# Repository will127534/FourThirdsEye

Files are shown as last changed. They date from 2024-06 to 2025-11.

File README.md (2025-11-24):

# FourThirdsEye: Opensource Micro Four Thirds camera module based on IMX294
_DSC0208

## Introduction
Welcome to the **FourThirdsEye** project, an open-source camera board designed for Raspberry Pi 5 and Raspberry Pi Compute Module 4 boards using a Micro Four Thirds format image sensor IMX294. This project aims to provide a high-quality and accessible camera module for advanced Raspberry Pi projects. The board is designed using KiCad v8.

FourThirdsEye captures 10.7 Mpix images and 4K (4096 x 2160) videos with improved low-light performance and dynamic range (4.63 um pixel size). It's perfect for photography enthusiasts, developers, and makers who want to level up their Raspberry Pi projects with a powerful camera.

Also see [Quick Start Guide](https://github.com/will127534/FourThirdsEye/wiki/FourThirdsEye-Quick-Start-Guide)

## Features
* **Open-source hardware and software**
* IMX294 sensor
* Integrated TMP117 temperature sensor
* Integrated ICM-42688-P 6-axis IMU with FSYNC connected to sensor's VSYNC
* Compatible with Raspberry Pi5 and Raspberry Pi Compute Module 4 boards with a 22-pin FPC connector and 4-lane MIPI-CSI (same pinout as Raspberry Pi Compute Module 4 IO Board)

## Notes
* Gerber, BOM and CPL file for JLCPCB is under [/Gerber](/Gerber)
* [Interactive BOM](https://htmlpreview.github.io/?https://github.com/will127534/FourThirdsEye/blob/main/ibom.html) [(provided by InteractiveHtmlBom)
](https://github.com/openscopeproject/InteractiveHtmlBom)
* Driver for Raspberry Pi: [https://github.com/will127534/imx294-v4l2-driver](https://github.com/will127534/imx294-v4l2-driver)
* 3D model for the board and sensor, C-mount adaptor and E-mount adaptor + Filter design is under [/3D_model](/3D_model), note that you will need to grab the metal ring from a E-mount (lens extender or replacements parts) and mount it to the 3D printed adaptor, for C-mount adaptor it is designed for CNC machine.
* Limited amount on [Tindle](https://www.tindie.com/products/will123321/fourthirdeye-v10/) for sell

## Sidenotes
IMX294 with CSI-2 interface mode is running at 1.78Gbps, technically breaking the spec for RPI5 (1.5Gbps) and CM4 (1Gbps?...they didn't really state it clearly) but I have tested on both platforms and are both working properly. But the one catch is that FPC cable quality/length will impact the data transmition, I've see black/bad pixel data scattering in the frames with a long 50cm cable, but it is fine with the 20cm cable. Also to actually utilized the full capacity/FPS of the sensor on RPI5, you will need to [overclock](https://www.willwhang.dev/Solar-eclipse-2024/#overclocking-the-rp1-for-enhanced-pisp-performance) RP1 (Camera Frontend) so it can handle the sensor at 60 FPS 4K. The sensor itself is also quite interesting because it is actually a quad bayer array just with subpixel combined output only, it is technically capable of sending high/low gain frame output but I'm still waiting for the HDR support on RPI5 to actually test it.

As for the PCB board design, the goal is to make a miniaturized camera board, but because of that I have to use smaller via sizes (0.2mm) and via-in-pad for the decoupling capacitors. There is also a bunch of tiny common mode CSI-2 filter that it might be hard for hand soldering so PCBA services or stencil + paste is the perfer way to build it.

Last thing is that if you are looking to capture RAW videos with Raspberry Pi 5, checkout [CinePi](https://github.com/cinepi/cinepi-sdk) from [@schoolpost](https://csabanagy.ca).

## Support
For questions, issues, or suggestions, please open an issue in the [GitHub repository](https://github.com/will127534/FourThirdsEye/issues)

## Schematic
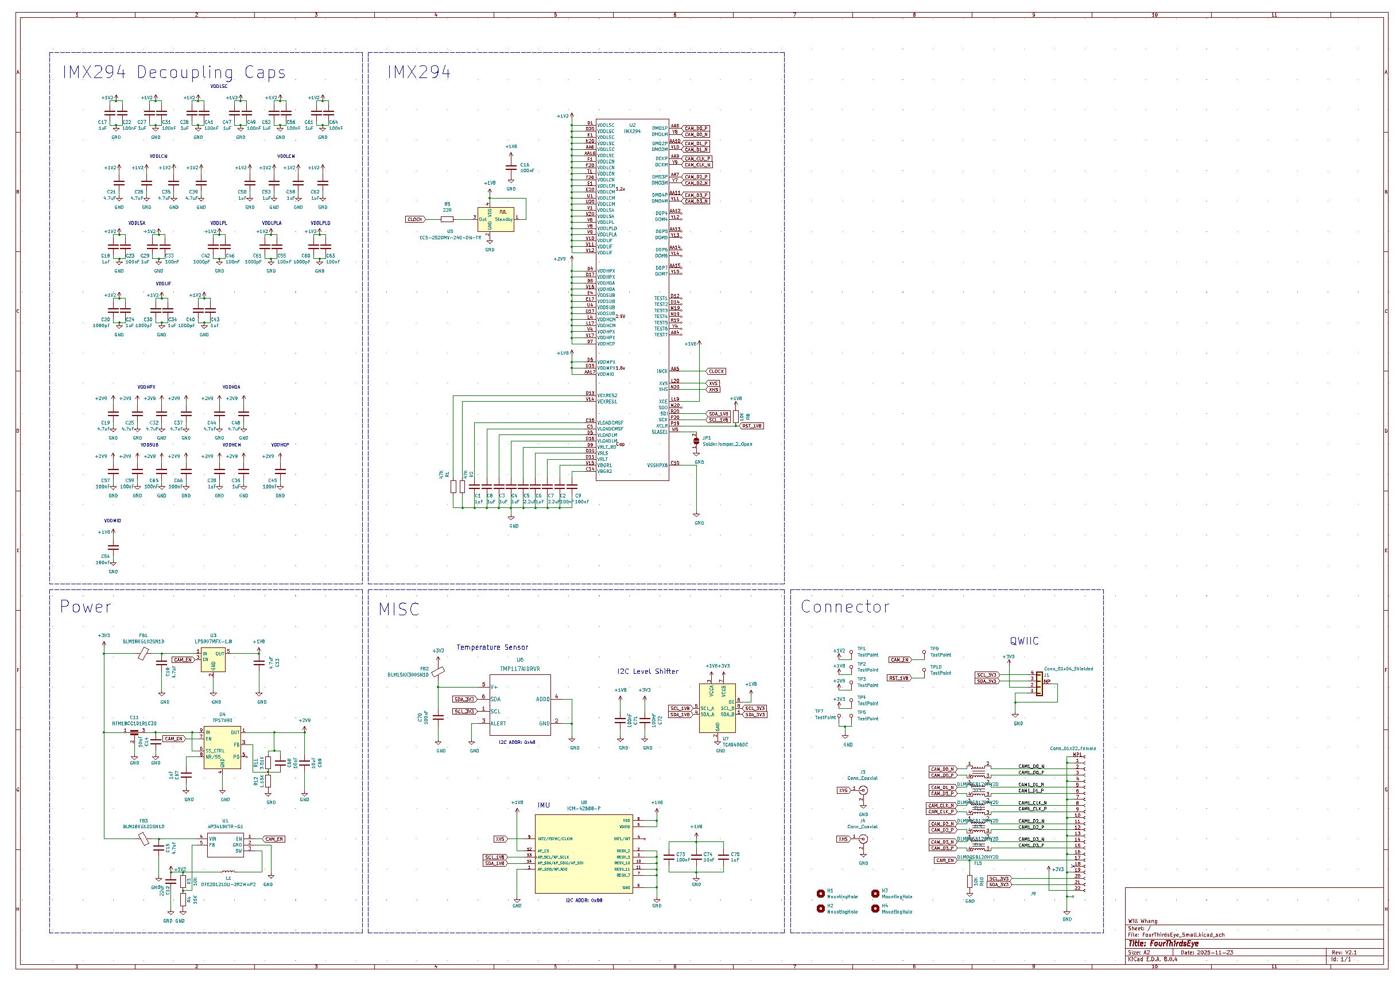
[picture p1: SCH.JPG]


## PCB
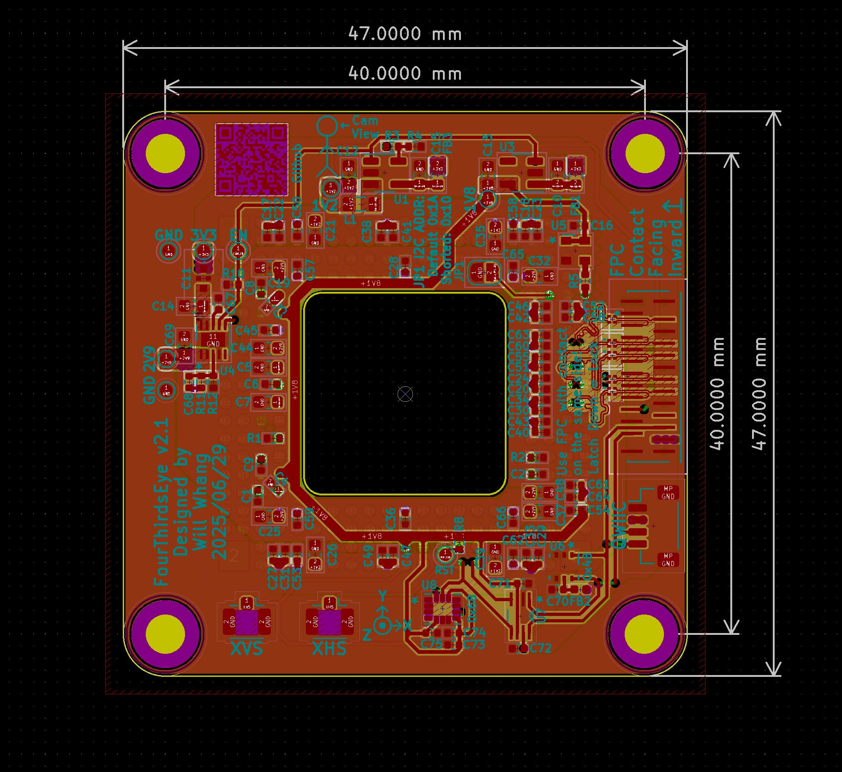
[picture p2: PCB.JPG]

*Screw hole sizes are M3

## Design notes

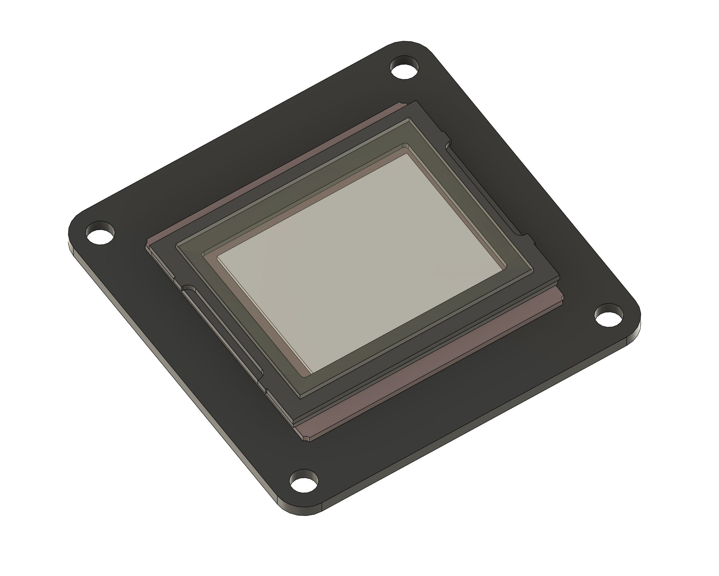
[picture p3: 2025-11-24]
3D_model/FourthirdEye_withSensor_V2.1.jpg

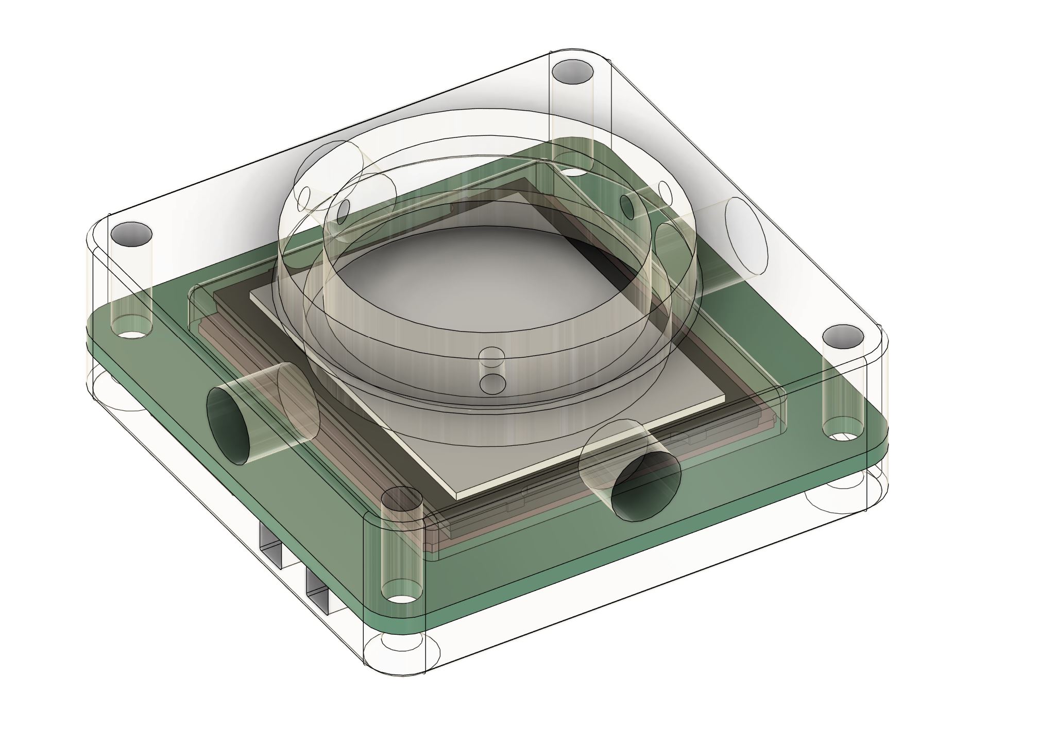
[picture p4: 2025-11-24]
3D_model/Cmount.jpg

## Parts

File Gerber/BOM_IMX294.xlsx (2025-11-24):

Comment | Designator | Footprint | JLCPCB Part #（optional）
1uF | C1,C36,C53,C4,C18,C6,C17,C75,C43,C62,C24,C28,C38,C61,C52,C50,C47,C67,C3,C8,C27,C34,C58,C29 | C_0402_1005Metric | C115046
C_Feedthrough | C11 | NFM18CC101R1C3D | C111493
22uF | C12 | C_0603_1608Metric | C59461
4.7uF | C32,C37,C44,C21,C13,C35,C10,C25,C39,C26,C19,C48,C15 | C_0603_1608Metric | C389010
2.2uF | C5,C7 | C_0603_1608Metric | C513691
1000pF | C60,C42,C20,C30,C51,C40 | C_0402_1005Metric | C338101
10nF | C68,C74 | C_0402_1005Metric | C15195
10uF | C69,C14 | C_0603_1608Metric | C2959727
100nF | C70,C41,C55,C45,C66,C46,C49,C31,C2,C22,C54,C59,C73,C56,C65,C64,C9,C71,C33,C57,C16,C72,C63,C23 | C_0402_1005Metric | C1525
BLM15AX300SN1D | FB2 | L_0402_1005Metric | C71813
BLM18KG102SN1D | FB3,FB1 | L_0603_1608Metric | C160982
DLM0QSB120HY2D | FL4,FL2,FL1,FL3,FL5 | DLM0QSB120HY2D | C3211477
QWIIC_CONNECTORJS-1MM | J1 | JST_SH_BM04B-SRSS-TB_1x04-1MP_P1.00mm_Vertical | C160390
Conn_Coaxial | J4,J3 | U.FL_Hirose_U.FL-R-SMT-1_Vertical | C5137195
Conn_01x22_Female | J9 | TF3822S05SV830 | C6552695
DFE201210U-2R2M=P2 | L1 | L_0805_2012Metric | C2049745
47K | R1,R2 | R_0402_1005Metric | C25792
10K | R10,R3,R4,R8 | R_0402_1005Metric | C25744
3.01K | R11 | R_0402_1005Metric | C304603
1.15K | R12 | R_0402_1005Metric | C477191
22R | R5 | R_0402_1005Metric | C413049
AP3418KTR-G1 | U1 | SOT-23-5 | C500769
LP5907MFX-1.8 | U3 | SOT-23-5 | C92498
TPS7A9001DSKR | U4 | Texas_S-PDSO-N10_EP1.2x2mm | C840111
ECS-2520MV-240-DN-TR | U5 | Oscillator_SMD_Abracon_ASDMB-4Pin_2.5x2.0mm | C5375391
TMP117AIDRVR | U6 | TMP117AIDRVR | C699536
TCA9406DC | U7 | TCA9406DCUR | C840107
ICM-42688-P | U8 | PQFN50P300X250X97-14N | C1850418

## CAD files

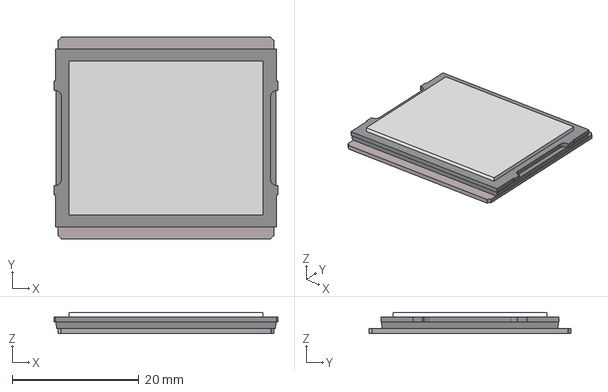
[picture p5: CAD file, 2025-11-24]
3D_model/IMX294.step
35.4 x 32.0 x 3.36 mm

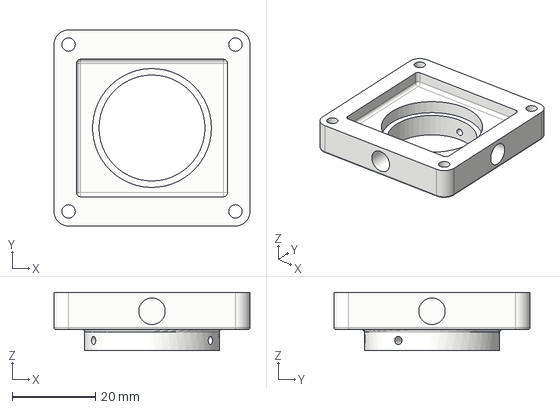
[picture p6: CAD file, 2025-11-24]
3D_model/Cmount_FrontPlate.step
47.0 x 47.0 x 13.9 mm

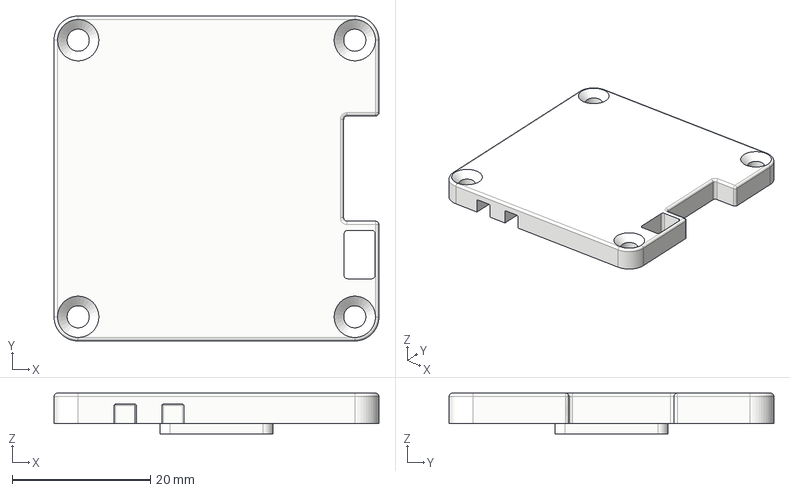
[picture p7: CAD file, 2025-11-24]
3D_model/Cmount_BackPlate.step
47.0 x 47.0 x 5.90 mm

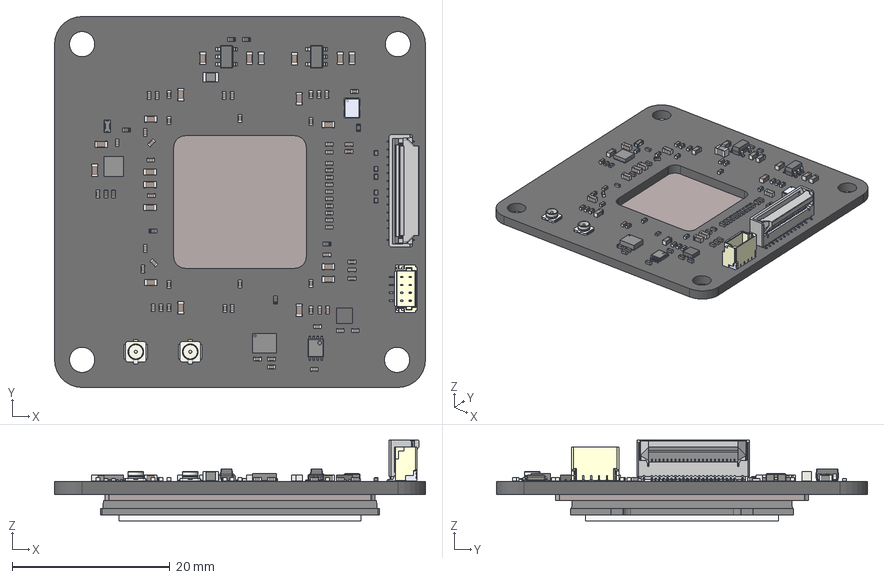
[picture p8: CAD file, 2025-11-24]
3D_model/FourthirdEye_withSensor_V2.1.step
47.0 x 47.0 x 10.2 mm
DLM0QSB120HY2D x 5
R_0402_1005Metric_1 x 9
ECS-2520S18-050-EN-TR
C_0402_1005Metric_1 x 56
U.FL_Hirose_U.FL-R-SMT-1_Vertical_1 x 2
ICM-42688-P_1
C_0603_1608Metric_1 x 18
DRV0006B_ASM
SOT_23_5 x 2
BM04B-SRSS-TBT(LF)(SN)
L_0805_2012Metric_1
L_0603_1608Metric_1 x 2
L_0402_1005Metric_1
TF38-22S-0.5SV_T
DCU0008A_ASM
NFM18PS105R0J3D_1
DSK0010A_ASM
_autosave-FourThirdsEye_Small_PCB
IMX294

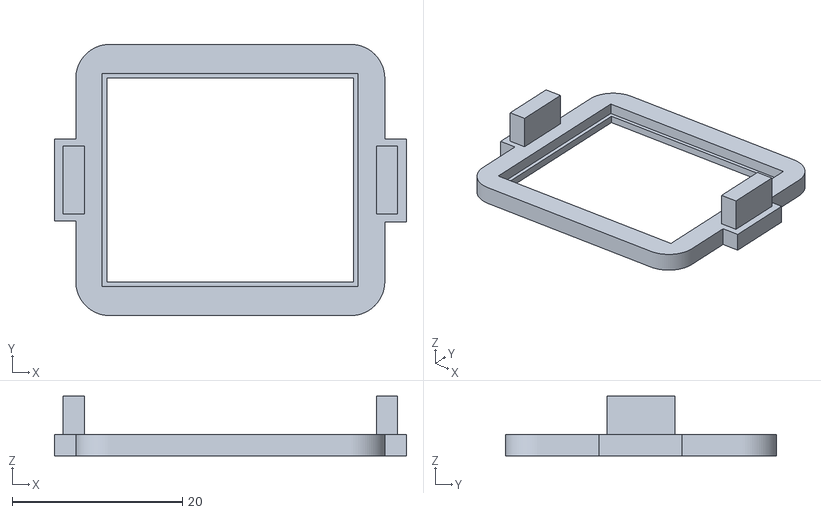
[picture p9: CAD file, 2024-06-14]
3D_model/FilterMount.stl
41.4 x 31.9 x 7.00

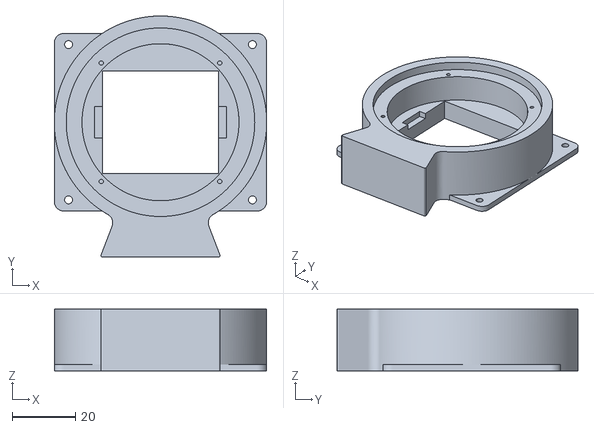
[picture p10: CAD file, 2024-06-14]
3D_model/Emount.stl
67.0 x 76.0 x 19.5

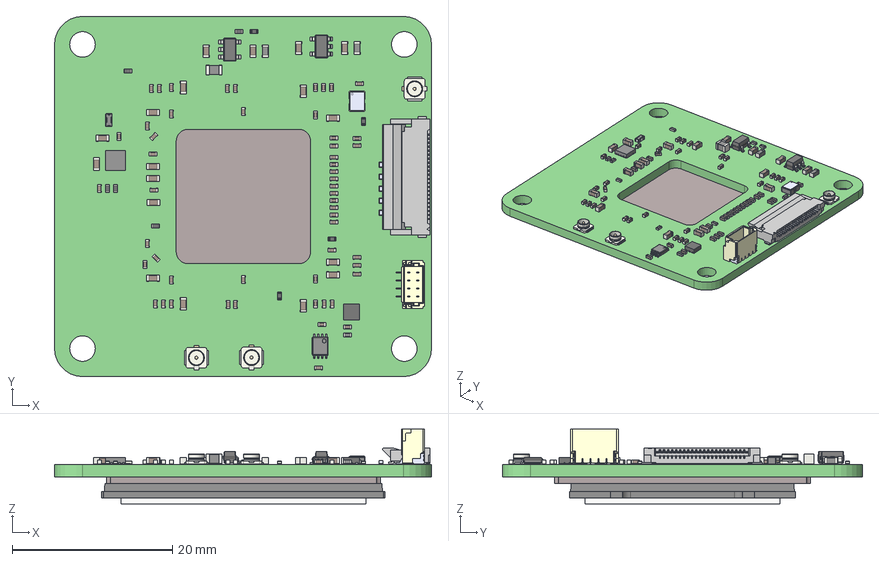
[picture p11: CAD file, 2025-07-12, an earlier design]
3D_model/FourthirdEye_withSensor_V2.step
47.1 x 45.0 x 9.36 mm
IMX294_MIPI_Breakout_Small PCB
IMX294

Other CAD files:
3D_model/FourthirdEye_withSensor_V2.1.stl

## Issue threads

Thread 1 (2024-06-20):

Availability

pterodyne, 2024-06-20:
Just asking, do you have any intention of building/selling such a board?  Id love to make my own m43 camera.

What about availability of the 283 based boards? I see they are out of stock now.
Thank you

Bryan

will127534, 2024-07-04:
I'm still debating about building a batch of this board, the main reason being that raw sensor cost are too high while you also need a certain amount to average the cost. (Not saying that I need to do 100+ but even with 20 boards, that means at least I need to put 2400 USD down just for the raw sensors). I don't think I'm gonna able to sell any of them at 399 USD and at this price it feels too risky for me.

While on the same time IMX294 is not that interesting for me personally (Resolution being the biggest issue, I want to have ~2.4um pixel size to match my telescope), I've also read the comments at Cloudynights and the response doesn't look that promising as a astrocamera either.

So in general I do recommend to build this board yourself if you are somewhat familiar with PCB design, I'm sure it will be faster then waiting for me to put it on the store.

As for the OneInchEye I'm planning to do another batch later this month.

gehelem, 2024-07-04:
hi
What about imx294 availability ?
Where do you find it ?
great project btw !
G.

fiveseven808, 2024-07-14:
I'm very interested in this. resolution could use work, but I'm super curious in building my own m43 camera. I don't mind ordering and populating the boards, but where can i get that sensor?!

Damme, 2024-07-14:
Also asked about sourcing the sensor on twitter without answer. Please share your information!

small-round-object, 2024-09-15:
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

Are you still planning on doing another batch of the oneincheye? I have checked your tindie page a few times with no luck.

will127534, 2024-09-29:
> Are you still planning on doing another batch of the oneincheye? I have checked your tindie page a few times with no luck.

Yes

> I ended up getting an ASI 2600MM with an IMX571. That would make a great still camera! but obviously for even more expense. If you have at 294 already made you could use binning which works great. I always used the 2 or 3x bin with my 304mm RC telescope, but I even did some planetary photos using full resolution and ROI.
>
> +1 on a 1 inch eye. It would work great for an initial experiment with a C mount ICL.

What's ICL?

Fun fact - you can find IMX571 datasheet too, the only issue I'm facing is how to capture the SLVS-EC.

will127534, 2024-09-29:
I have a CM4 camera module board used here: https://www.willwhang.dev/SolarImaging/

Riner06, 2024-10-05:
@gehelem did you find where to source the imx294 sensor? I'm currently looking for it. Kind regards an aspiring engineer

gehelem, 2024-10-05:
> @gehelem did you find where to source the imx294 sensor? I'm currently looking for it. Kind regards an aspiring engineer

Nope
G.

XinmiaoZhao, 2024-12-24:
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

Hi, did you find a way to capture the SLVS-EC using either RPi or other boards (maybe FPGA)?

aethersis, 2025-03-20:
You mentioned one board with the sensor could be built for around $400 - is that still up to date? I'd gladly pay you for this.

will127534, 2025-03-21:
Will be on Tindle later this week.

@pterodyne
> Trying to make a larger sensor still camera around a CM5. PiSLR if you will.
Specifically the reason why I lost my interest in this is exactly because I want to do still camera more than video recorder : D
IMX294 is design for 4K recording specifically, so it isn't great (aspect ratio, resolution-wise).

I'm currently working on IMX269 (20Mpixel, M4/3 sensor) so will see how that goes.

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

will127534, 2025-03-22:
> Do you have an estimate for the IMX269 project? I for one would be quite interested in this module!

The difference between work and hobby is commitment : D
Will see how that goes but no promises - I have the board mostly done back in Jan but haven't send it out to fab yet, lol.

will127534, 2025-03-26:
https://www.tindie.com/products/will123321/fourthirdeye-v10/

aethersis, 2025-04-30:
> https://www.tindie.com/products/will123321/fourthirdeye-v10/

Looks like it's already out of stock, but once I get my hands on one, I can provide an ISP tuning file for this since I have access to a professional imaging lab in one of the major camera manufacturing companies and am in touch with people from libCamera (Ideas on Board) and can ask them for help.

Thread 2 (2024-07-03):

With the help of my mother and home oven (and JLCPCB, of course), I successfully reproduced this project! ! !

MaxMiao95, 2024-07-03:

gkyle, 2024-07-03:
Looks promising! I think I'll build a couple of these too. Looking at JLCPCB, they don't have a few parts in stock for PCBA:
- Common Mode Filters: DLM0QSB120HY2D
- 24 MHz Oscillator: ECS-2520MV-240-DN-TR
- Step-down Voltage Regulator: AP3429KTTR-G1 (Alternative: TLV62569)
Some of these have obvious alternatives but the first 2 did not. Just curious if you were able to get everything from JLC stock, found reasonable alternatives (if so, would love to see which), or just sourced them and soldered them yourself. Thanks!

MaxMiao95, 2024-07-04:
Find them, send them to jlcpcb, and after paying for the replacement fee, they will stick them for you.

MaxMiao95, 2024-07-04:
Special reminder to pay attention to packaging and specifications

ankushDhawan5812, 2024-10-02:
Where were you able to find the camera module? I am trying to find places to buy just the camera module from, but am unable to find anything promising.

Riner06, 2024-10-05:
@ankushDhawan5812 where you able to find where to buy the imx294 camera sensor?

mouseos, 2025-02-12:
@MaxMiao95 How much did the cost end up being?

MaxMiao95, 2025-02-12:
About $1100 For 5 pcs，if you only want get 1 pcs，about $500。I use jlcpcb to make those pcbs。Actually，The imx585 camera is better than this one，i suggest you just buy them（starlighteye） from will'shop。 imx294 have some defects……

Young-JZ-Wang, 2025-07-05:
@MaxMiao95 I'm new to the camera design. I wonder if the IMX585 and IMX294 are interchangeable in this case?

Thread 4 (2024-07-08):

I'm wondering about the functions of the chokes.

NightFuryAstro, 2024-07-08:
FL1 to FL5 are chokes with cutoff frequency of 8GHz, and I'm wondering about their function. According to the datasheet of IMX294CJK, there is no need of adding chokes on the output side. Are these chokes necessary? May I just replace it with wires?

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

will127534, 2024-07-08:
Those are common mode chokes - made for canceling out high frequency noises.
They are not necessary for sure, but something nice to have. By removing the chokes I'm not sure how that will impact your maximum FPC length but you can try.

NightFuryAstro, 2024-07-08:
Thanks!

Closed 2024-07-08.

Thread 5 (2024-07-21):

STEP file in /Models appears to be out of date

ThyOwen, 2024-07-21:
I just imported the files into fusion and they bare a different set of dimensions and layout from those in schematics and pictures. Is this an older version of the project?
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

will127534, 2024-07-21:
Yeapppp, that is the full-size version. I'll update the step soon

will127534, 2024-07-22:
Should be fixed by now.

Closed 2024-07-22.

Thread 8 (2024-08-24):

Datasheet

will127534, 2024-08-24:
https://www.eoshd.com/comments/topic/28132-sony-sensor-imx294-full-datasheet-bmpc-4k-z-cam-e2-gh5s/

will127534, 2025-03-19:
[IMX294_SupportPackage_E_Rev0.1.pdf](https://github.com/user-attachments/files/19332883/IMX294_SupportPackage_E_Rev0.1.pdf)

[IMX294CJK-C_E_Datasheet_E17405B7Z.pdf](https://github.com/user-attachments/files/19332922/IMX294CJK-C_E_Datasheet_E17405B7Z.pdf)

For backup reasons

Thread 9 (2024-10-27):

Do the differential pairs need to have equal lengths?

WaterBlock623, 2024-10-27:
I want to modify the PCB but I can't find the SLVS-EC Standard in the Support Package.
What is the allowable skew between each lane(CAM_Dx_x and CAM_CLK_x)?

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

will127534, 2024-10-27:
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
This is the best I can find, which receiver are you going to use?

WaterBlock623, 2024-11-04:
Thanks. I am using RPi 5. I calculated the maximum length difference to be approximately 40 cm (5 SI, 50 ps/cm, 2.3 Gbps). Is this data correct?

will127534, 2025-02-01:
Not sure, the datasheet isn't really giving me correct numbers

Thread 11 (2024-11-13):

Autofocus?

Verhulstak, 2024-11-13:
i just discovered this project and i would like to use it in one of my project. The project is basically a action camera but its a cm4 but i need autofocus
so do you have a solution to that or is it possible to mod it in?

jockm, 2025-01-04:
@Verhulstak Autofocus is a function of the lens and software working together.  The sensor itself cannot change the focus.  So you would need to do something like adapt the sensor to take a micro four thirds lens, and then write software to do the focusing.

Closed 2025-03-19.

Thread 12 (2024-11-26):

picamera

MaxMiao95, 2024-11-26:
ImportError: /usr/lib/python3/dist-packages/libcamera/_libcamera.cpython-311-aarch64-linux-gnu.so: undefined symbol: _ZN9libcamera8controls3rpi20CnnEnableInputTensorE

MaxMiao95, 2024-11-26:
Failed to generate valid configuration
[0:14:43.249947165] [2770] ERROR Camera camera.cpp:587 Removing camera while still in use

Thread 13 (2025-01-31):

FFC cable type

kaichodesu, 2025-01-31:
Should I be using a reversed FFC cable or not?

Closed 2025-01-31.

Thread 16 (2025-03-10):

Could somone generate a .STEP file with the sensor on it?

cazvoorhees, 2025-03-10:
That would be greatly appreciated so i could get the correct distance between the lens and the sensor.

will127534, 2025-07-12:
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

Closed 2025-07-12.

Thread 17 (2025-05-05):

Thanks - Potential Use in WildCamera Open Source Wildlife Camera

William-Robert-Robertson, 2025-05-05:
Hi Will,

Thank you very much for designing and open sourcing the FourThridsEye camera!

I'm working on a fully open source wildlife camera and thought I'd get in touch to see if you think we could use the FourThridsEye camera in it?

The plan is to use a modern SoM with MIPI CSI-2 interface, good ISP and good open source support connected to 1 or 2 MIPI CSI-2 cameras. Connecting to 2 cameras can be helpful because it allows separate RGGB day time and high sensitivity monochrome visible and IR image sensors for night time use without the added complexity of a MIPI CSI-2 multiplexer. At the moment the best SoM seems to be the NXP i.MX 8M Plus.

We'll use embedded Linux and libcamera so that users have a lot of flexibility but may try to develop an ultra-low-power bare metal or RTOS version in the future if resources allow.

Our GIT repository is here:

https://github.com/William-Robert-Robertson/WildCamera

some of our conservation work here:

https://new-homes-for-old-friends.cairnwater.com/

Will

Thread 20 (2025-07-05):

Jetson Nano support, monochrome option, IMX294 STEP file, and Tindie restock

Young-JZ-Wang, 2025-07-05:
Pardon my beginner questions, and first of all—this is a fantastic repo and project!

1. Is this designed for Raspberry Pi only, or does it also support Jetson Nano?
2. Is it possible to have a monochromatic version?
3. Where did you get the IMX294 sensor and the STEP file for it?
4. I see the Tindie shop is out of stock, when will the new batch be out?

Thanks in advance for your time!

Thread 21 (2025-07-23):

The camera does not take pictures properly

everything-maker, 2025-07-23:
I have this problem after installing the driver
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

everything-maker, 2025-07-23:
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

everything-maker, 2025-07-23:
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

will127534, 2025-07-23:
Here is the correct orientation:

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

everything-maker, 2025-07-27:
I still get the same error after re-soldering😥

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

eva-00100, 2025-07-27:
I used a meter to detect their on/off and it seemed to be fine🤔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

eva-00100, 2025-07-27:
I'm more worried that my sensor is broken🥹

eva-00100, 2025-07-27:
The problem was solved, two false solder joints on the filter were found, thanks for your help

Closed 2025-07-27.

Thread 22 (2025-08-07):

Questions about drives

eva-00100, 2025-08-07:
I tried shooting in 14bit mode, but there is a problem with the photo I took Would I like to ask if this is a driver problem? (It's normal when shooting in 12bit mode) Please answer for me when you have time, thank you

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

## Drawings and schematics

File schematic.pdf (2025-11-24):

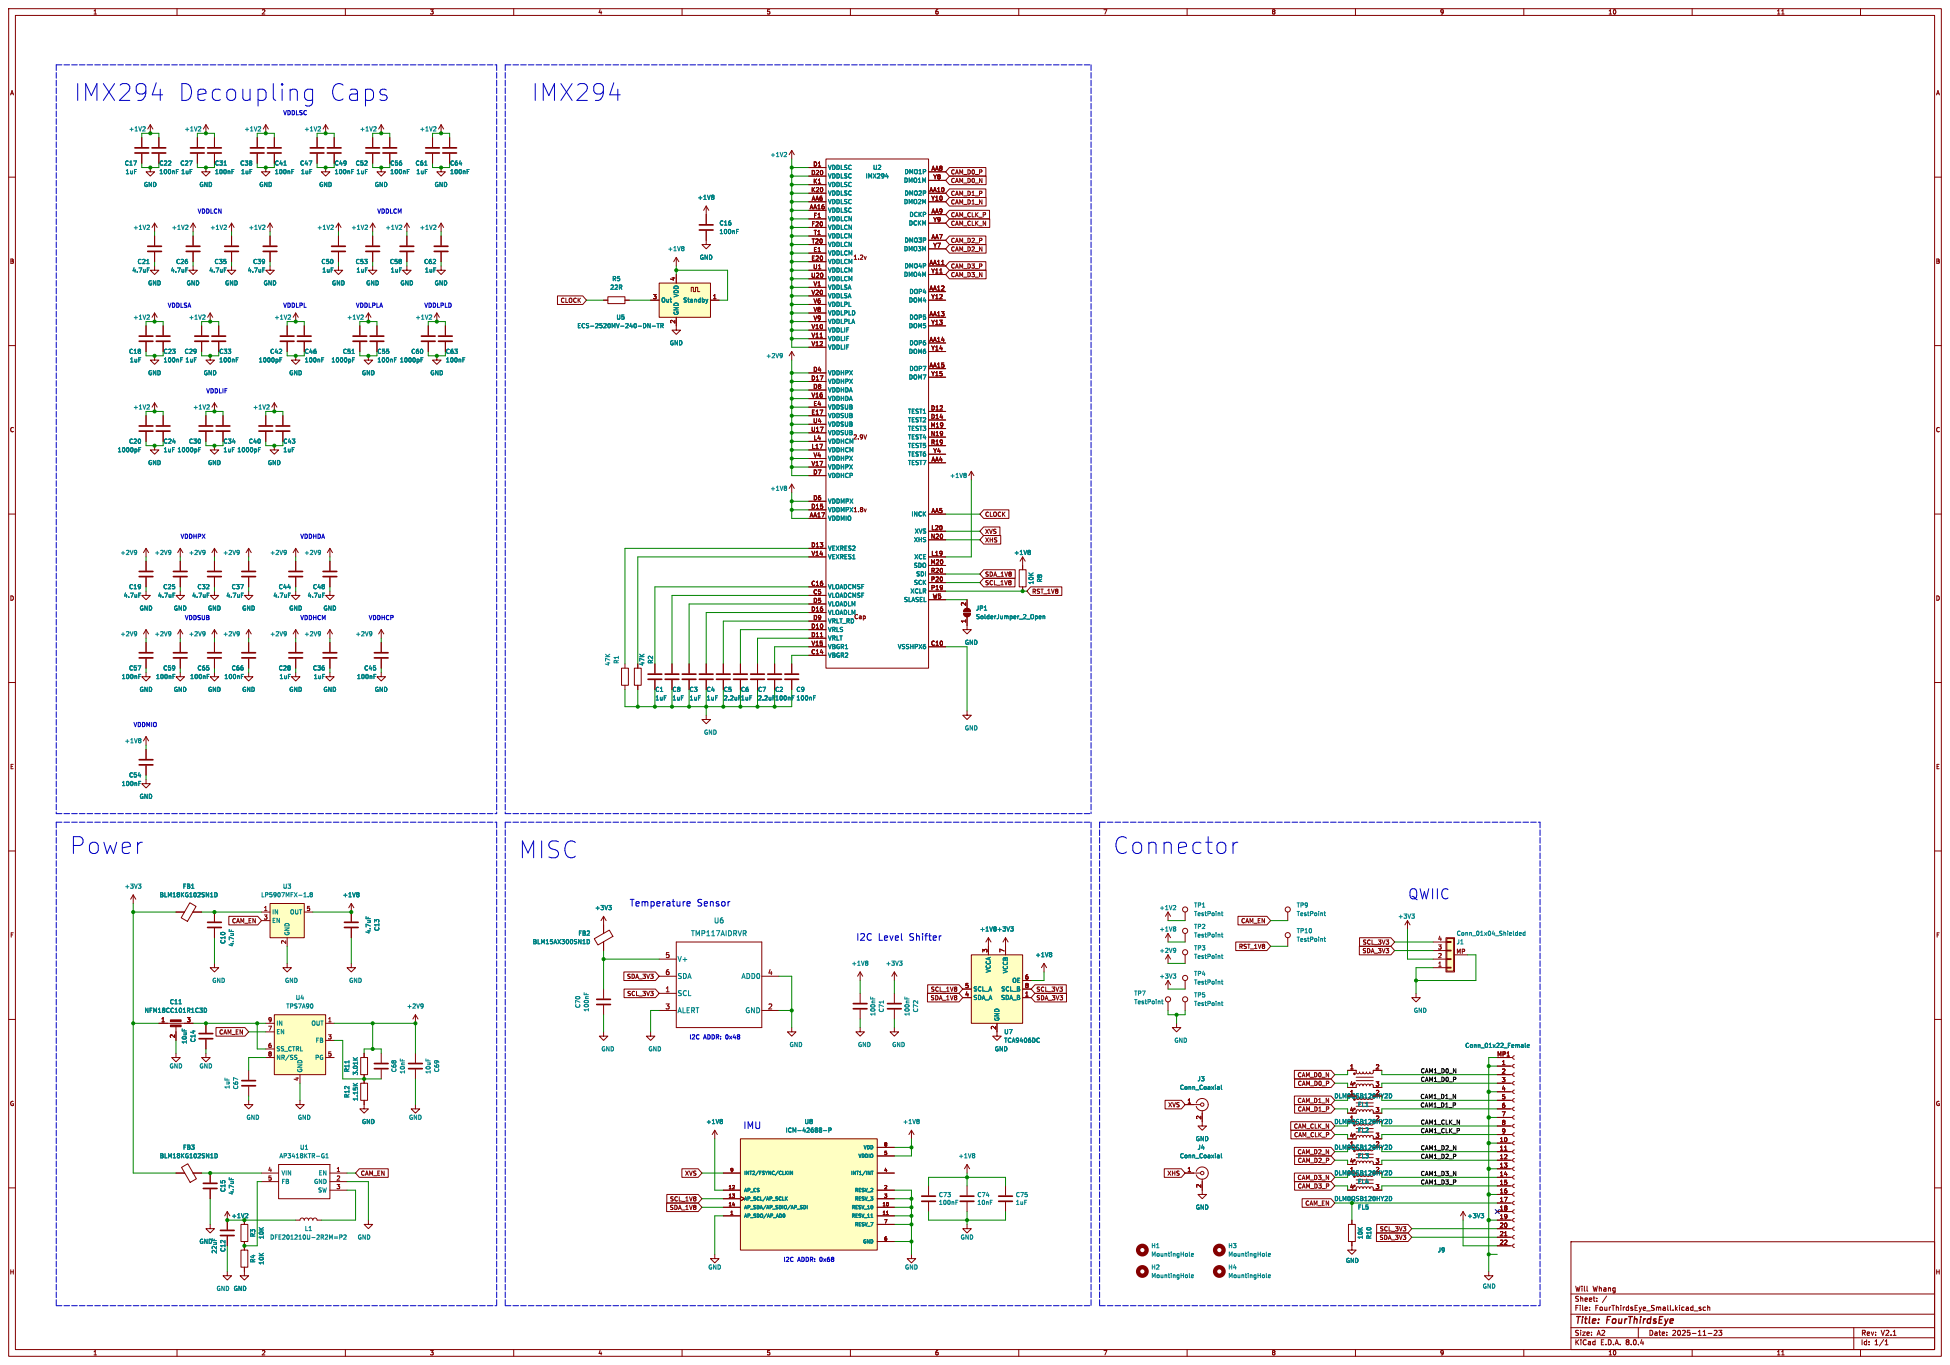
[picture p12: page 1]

4 PG 5 SS_CTRL 6 EN 7 NR/SS 8

File: FourThirdsEye_Small.kicad_sch Sheet: / Will Whang

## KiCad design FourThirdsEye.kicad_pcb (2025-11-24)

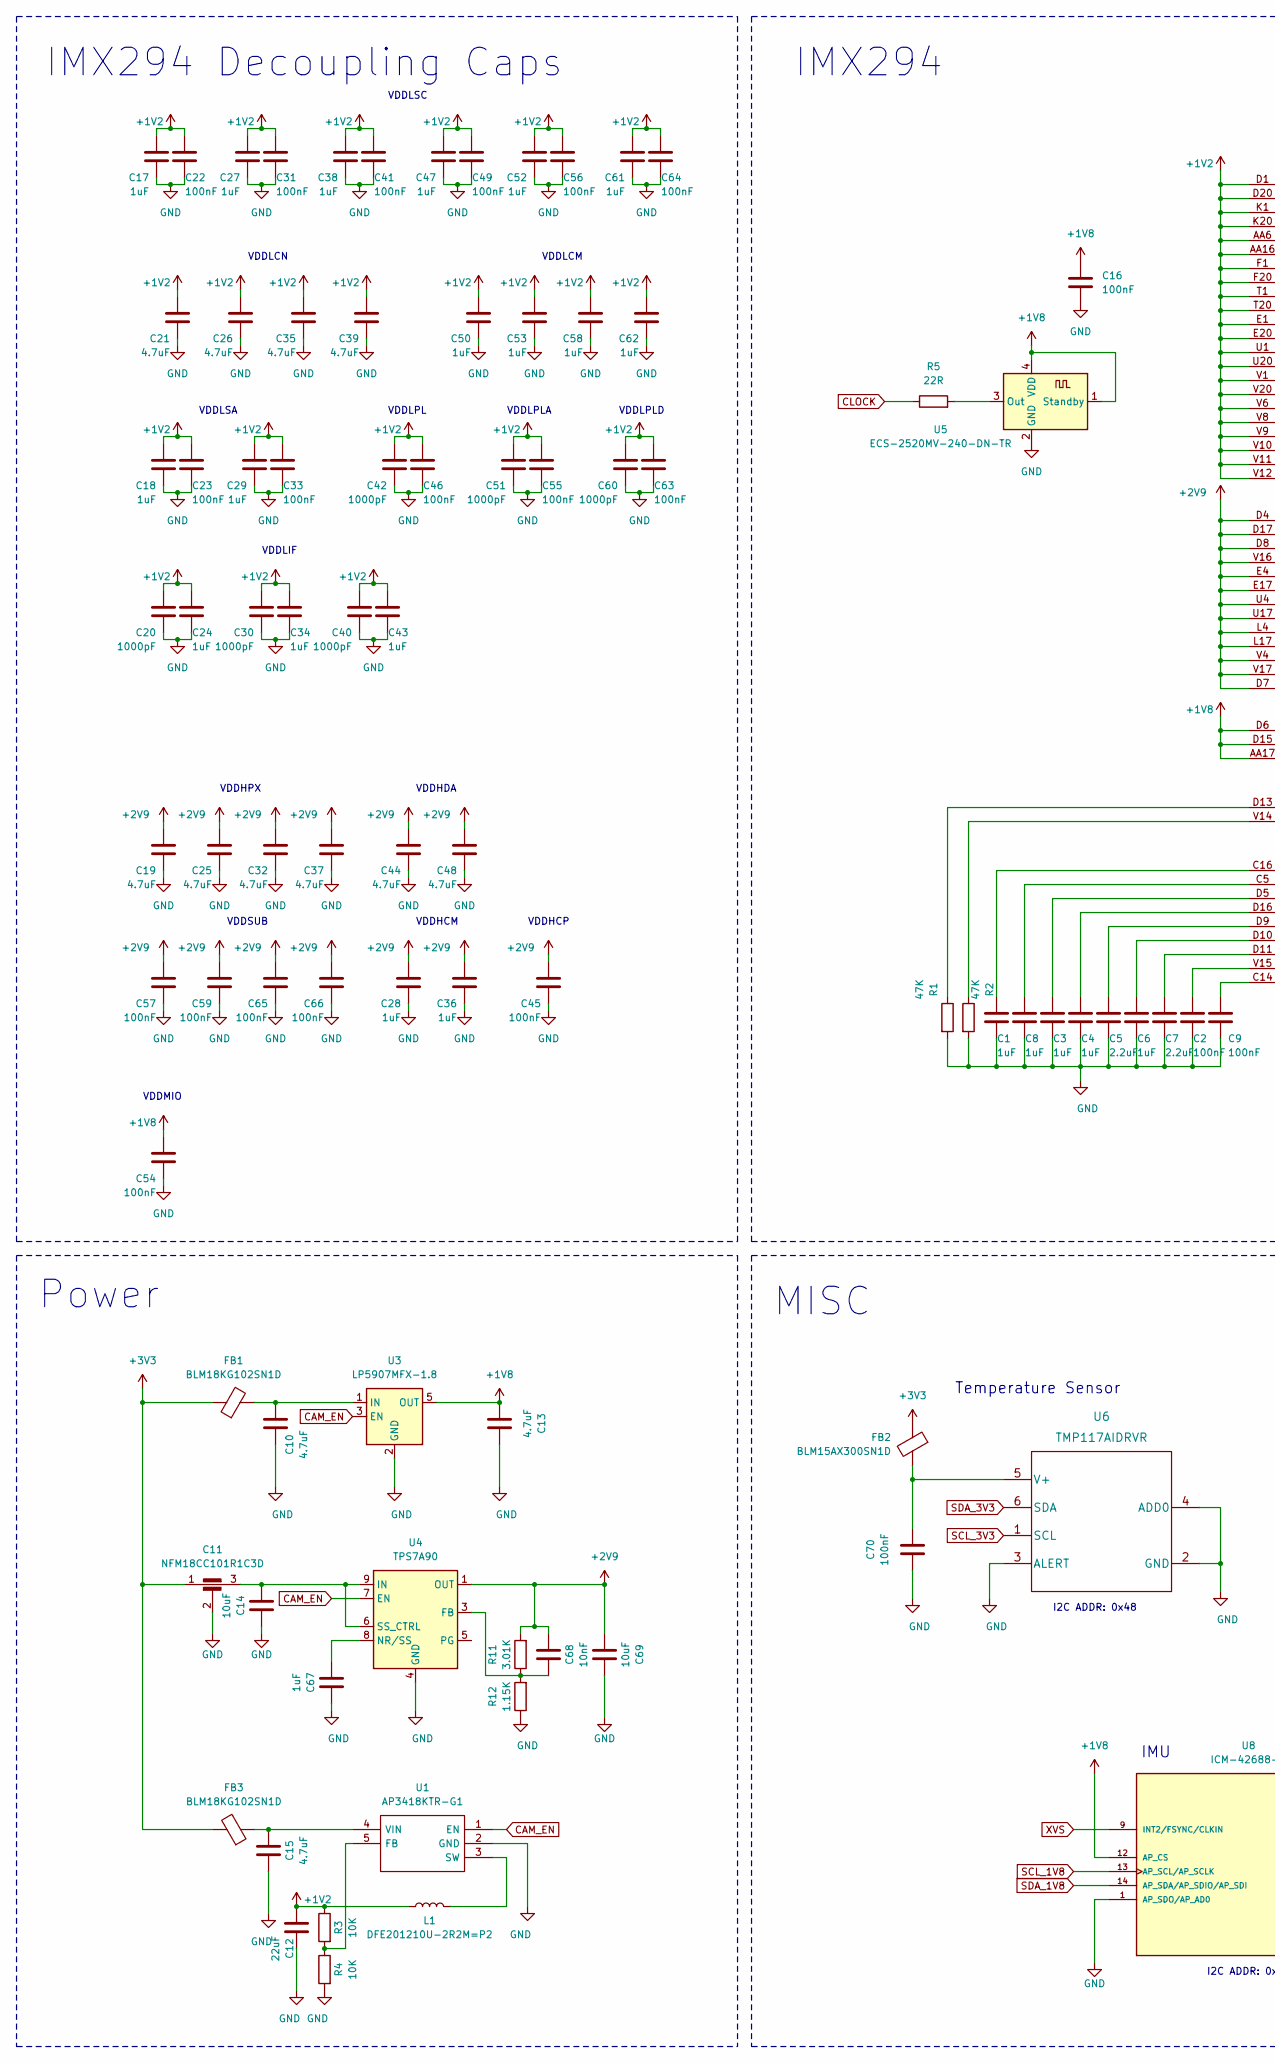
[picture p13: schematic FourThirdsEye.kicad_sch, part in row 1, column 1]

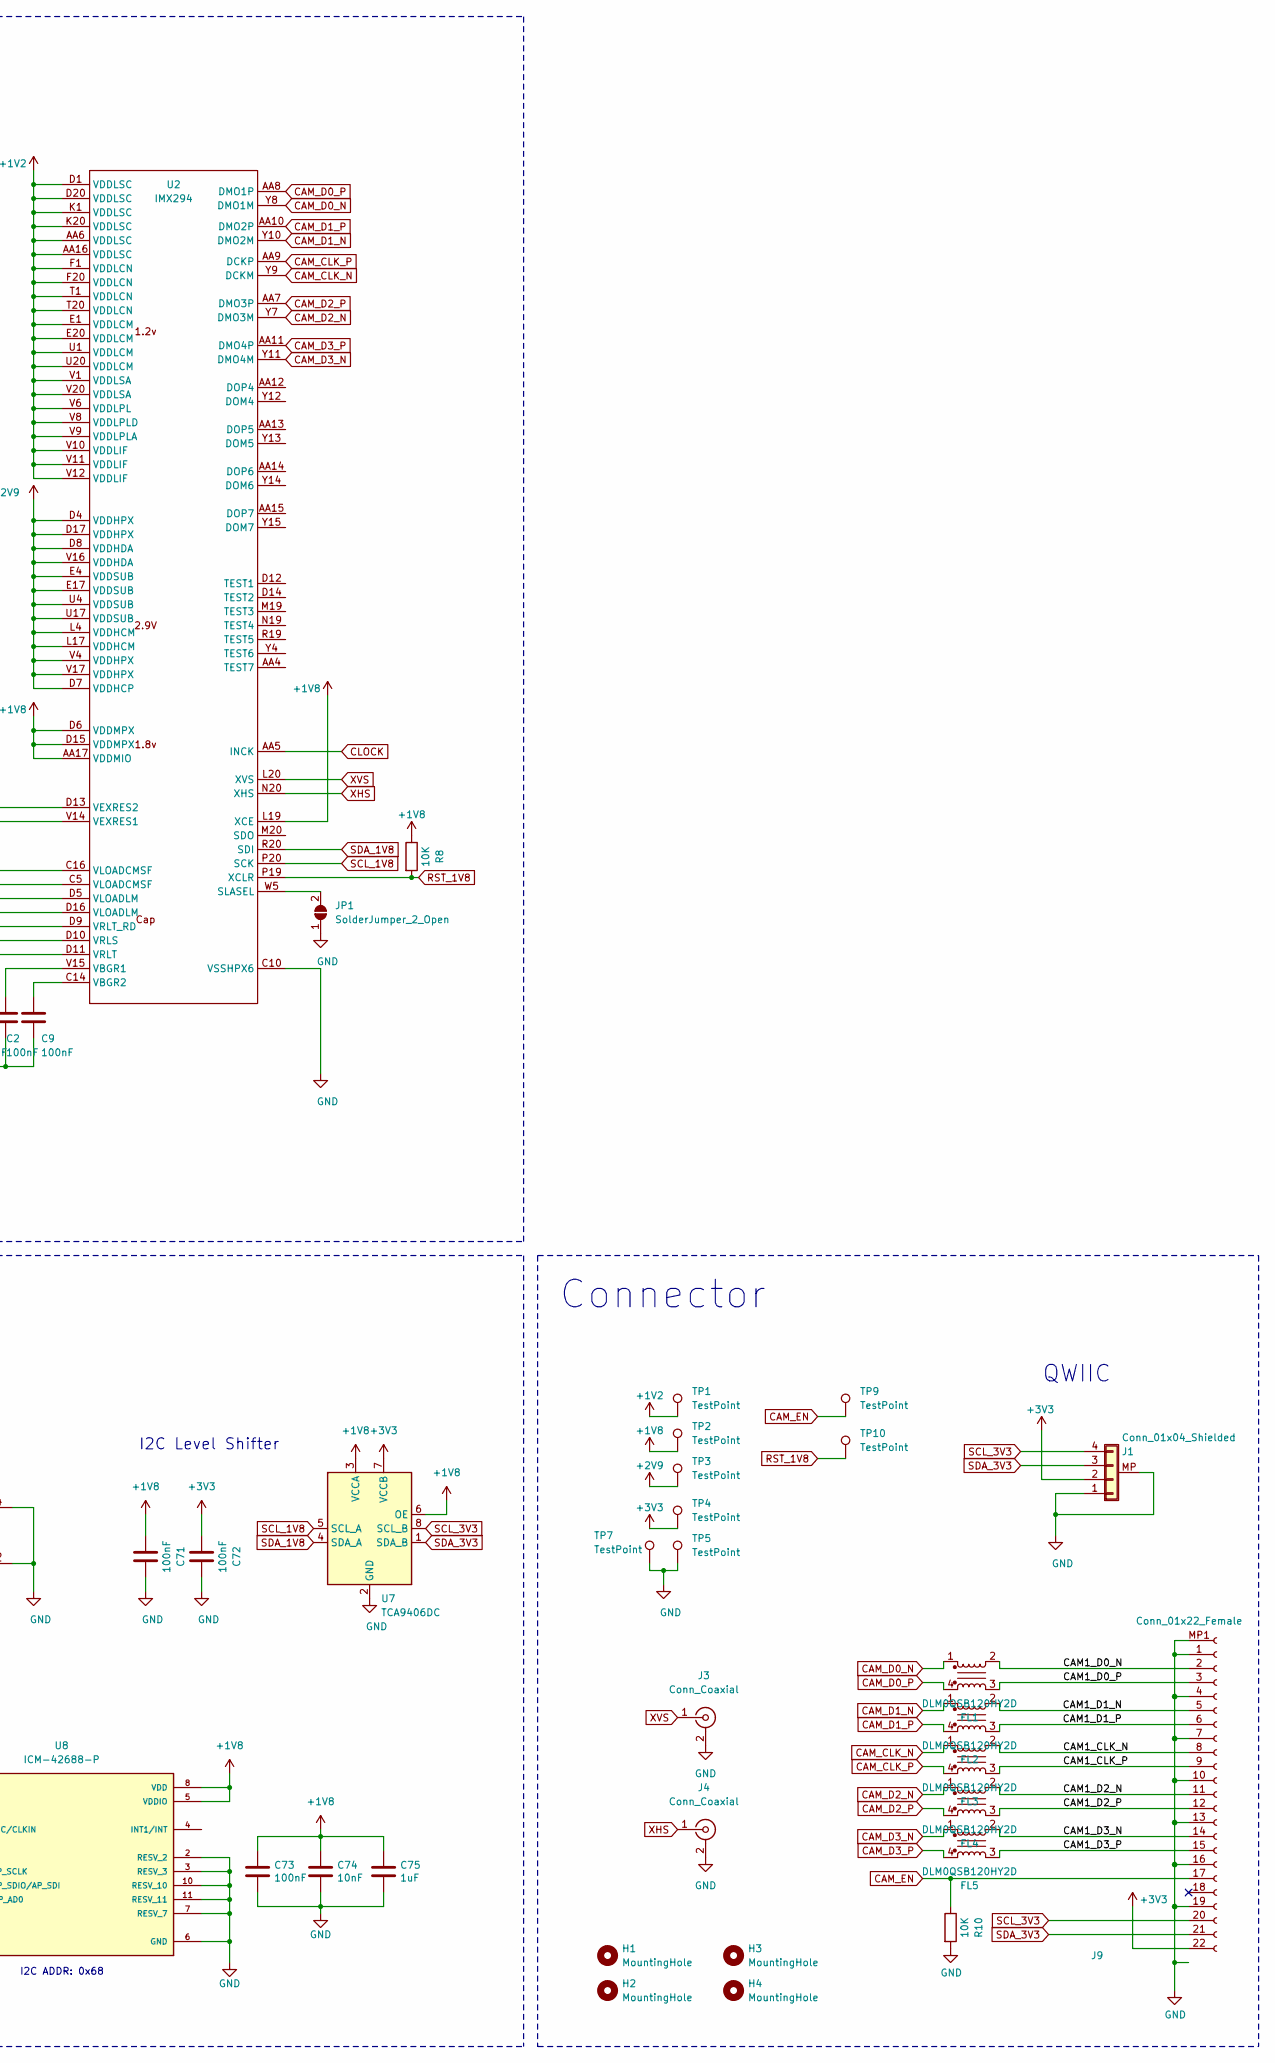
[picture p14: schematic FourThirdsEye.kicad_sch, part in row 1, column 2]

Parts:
C1, C3, C4, C6, C8, C17, C18, C24, C27, C28, C29, C34, C36, C38, C43, C47, C50, C52, C53, C58, C61, C62, C67, C75: 1uF; C_0402_1005Metric
C2, C9, C16, C22, C23, C31, C33, C41, C45, C46, C49, C54, C55, C56, C57, C59, C63, C64, C65, C66, C70, C71, C72, C73: 100nF; C_0402_1005Metric
C5, C7: 2.2uF; C_0603_1608Metric
C10, C13, C15, C19, C21, C25, C26, C32, C35, C37, C39, C44, C48: 4.7uF; C_0603_1608Metric
C11: NFM18CC101R1C3D
C12: 22uF; C_0603_1608Metric
C14, C69: 10uF; C_0603_1608Metric
C20, C30, C40, C42, C51, C60: 1000pF; C_0402_1005Metric
C68, C74: 10nF; C_0402_1005Metric
FB1, FB3: BLM18KG102SN1D; L_0603_1608Metric
FB2: BLM15AX300SN1D; L_0402_1005Metric
FL1, FL2, FL3, FL4, FL5: DLM0QSB120HY2D
H1, H2, H3, H4: MountingHole; MountingHole_3.2mm_M3
J1: Conn_01x04_Shielded; JST_SH_BM04B-SRSS-TB_1x04-1MP_P1.00mm_Vertical
J3, J4: Conn_Coaxial; U.FL_Hirose_U.FL-R-SMT-1_Vertical
J9: Conn_01x22_Female; TF3822S05SV830; Part Description 22 Position FFC, FPC Connector Contacts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
JP1: SolderJumper_2_Open; SolderJumper-2_P1.3mm_Open_RoundedPad1.0x1.5mm
L1: DFE201210U-2R2M=P2; L_0805_2012Metric
R1, R2: 47K; R_0402_1005Metric
R3, R4, R8, R10: 10K; R_0402_1005Metric
R5: 22R; R_0402_1005Metric
R11: 3.01K; R_0402_1005Metric
R12: 1.15K; R_0402_1005Metric
TP1, TP2, TP3, TP4, TP5, TP7, TP9, TP10: TestPoint; TestPoint_Pad_D1.0mm
U1: AP3418KTR-G1; SOT-23-5; Mouser Part Number 621-AP3418KTR-G1
U2: IMX294
U3: LP5907MFX-1.8; SOT-23-5
U4: TPS7A90; Texas_S-PDSO-N10_EP1.2x2mm
U5: ECS-2520MV-240-DN-TR; Oscillator_SMD_Abracon_ASDMB-4Pin_2.5x2.0mm
U6: TMP117AIDRVR
U7: TCA9406DC; TCA9406DCUR
U8: ICM-42688-P; PQFN50P300X250X97-14N; PARTREV 1.2

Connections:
+1V2: C12.2, C17.2, C18.2, C20.2, C21.2, C22.1, C23.1, C24.1, C26.2, C27.2, C29.2, C30.2, C31.1, C33.1, C34.1, C35.2, C38.2, C39.2, C40.2, C41.1, C42.2, C43.1, C46.1, C47.2, C49.1, C50.2, C51.2, C52.2, C53.2, C55.1, C56.1, C58.2, C60.2, C61.2, C62.2, C63.1, C64.1, L1.2, R3.1, TP1.1, U2.AA6 (VDDLSC), U2.AA16 (VDDLSC), U2.D1 (VDDLSC), U2.D20 (VDDLSC), U2.E1 (VDDLCM), U2.E20 (VDDLCM), U2.F1 (VDDLCN), U2.F20 (VDDLCN), U2.K1 (VDDLSC), U2.K20 (VDDLSC), U2.T1 (VDDLCN), U2.T20 (VDDLCN), U2.U1 (VDDLCM), U2.U20 (VDDLCM), U2.V1 (VDDLSA), U2.V6 (VDDLPL), U2.V8 (VDDLPLD), U2.V9 (VDDLPLA), U2.V10 (VDDLIF), U2.V11 (VDDLIF), U2.V12 (VDDLIF), U2.V20 (VDDLSA)
+1V8: C13.1, C16.1, C54.2, C71.1, C73.1, C74.1, C75.1, R8.1, TP2.1, U2.AA17 (VDDMIO), U2.D6 (VDDMPX), U2.D15 (VDDMPX), U2.L19 (XCE), U3.5 (OUT), U5.1 (Standby), U5.4 (VDD), U7.3 (VCCA), U7.6 (OE), U8.5 (VDDIO), U8.8 (VDD), U8.12 (AP_CS)
+2V9: C19.2, C25.2, C28.2, C32.2, C36.2, C37.2, C44.2, C45.2, C48.2, C57.2, C59.2, C65.2, C66.2, C68.2, C69.1, R11.2, TP3.1, U2.D4 (VDDHPX), U2.D7 (VDDHCP), U2.D8 (VDDHDA), U2.D17 (VDDHPX), U2.E4 (VDDSUB), U2.E17 (VDDSUB), U2.L4 (VDDHCM), U2.L17 (VDDHCM), U2.U4 (VDDSUB), U2.U17 (VDDSUB), U2.V4 (VDDHPX), U2.V16 (VDDHDA), U2.V17 (VDDHPX), U4.1 (OUT), U4.2 (OUT)
+3V3: C11.1, C72.1, FB1.1, FB2.1, FB3.2, J1.2, J9.22, TP4.1, U7.7 (VCCB)
/CAM1_CLK_N: FL3.2, J9.8
/CAM1_CLK_P: FL3.3, J9.9
/CAM1_D0_N: FL1.2, J9.2
/CAM1_D0_P: FL1.3, J9.3
/CAM1_D1_N: FL2.2, J9.5
/CAM1_D1_P: FL2.3, J9.6
/CAM1_D2_N: FL4.2, J9.11
/CAM1_D2_P: FL4.3, J9.12
/CAM1_D3_N: FL5.2, J9.14
/CAM1_D3_P: FL5.3, J9.15
CAM_CLK_N: FL3.1, U2.Y9 (DCKM)
CAM_CLK_P: FL3.4, U2.AA9 (DCKP)
CAM_D0_N: FL1.1, U2.Y8 (DMO1M)
CAM_D0_P: FL1.4, U2.AA8 (DMO1P)
CAM_D1_N: FL2.1, U2.Y10 (DMO2M)
CAM_D1_P: FL2.4, U2.AA10 (DMO2P)
CAM_D2_N: FL4.1, U2.Y7 (DMO3M)
CAM_D2_P: FL4.4, U2.AA7 (DMO3P)
CAM_D3_N: FL5.1, U2.Y11 (DMO4M)
CAM_D3_P: FL5.4, U2.AA11 (DMO4P)
CAM_EN: J9.17, R10.1, TP9.1, U1.1 (EN), U3.3 (EN), U4.7 (EN)
CLOCK: R5.1, U2.AA5 (INCK)
GND: C1.2, C2.2, C3.2, C4.2, C5.2, C6.2, C7.2, C8.2, C9.2, C10.1, C11.2, C12.1, C13.2, C14.2, C15.2, C16.2, C17.1, C18.1, C19.1, C20.1, C21.1, C22.2, C23.2, C24.2, C25.1, C26.1, C27.1, C28.1, C29.1, C30.1, C31.2, C32.1, C33.2, C34.2, C35.1, C36.1, C37.1, C38.1, C39.1, C40.1, C41.2, C42.1, C43.2, C44.1, C45.1, C46.2, C47.1, C48.1, C49.2, C50.1, C51.1, C52.1, C53.1, C54.1, C55.2, C56.2, C57.1, C58.1, C59.1, C60.1, C61.1, C62.1, C63.2, C64.2, C65.1, C66.1, C67.2, C69.2, C70.1, C71.2, C72.2, C73.2, C74.2, C75.2, J1.1, J1.MP (Shield), J3.2 (Ext), J4.2 (Ext), J9.1, J9.4, J9.7, J9.10, J9.13, J9.16, J9.19, J9.MP1 (Pin_MP), J9.MP2 (Pin_MP), J9.MP3 (Pin_MP), J9.MP4 (Pin_MP), JP1.1 (A), R1.2, R2.2, R4.2, R10.2, R12.1, TP5.1, TP7.1, U1.2 (GND), U2.C4 (VSSHPX1), U2.C6 (VSSHPX2), U2.C7 (VSSHCP3), U2.C8 (VSSHDA4), U2.C9 (VSSHPX5), U2.C10 (VSSHPX6), U2.C11 (VSSHPX7), U2.C12 (VSSHPX8), U2.C15 (VSSHPX9), U2.C17 (VSSHPX10), U2.D2 (VSSLSC11), U2.D19 (VSSLSC12), U2.E2 (VSSLCM13), U2.E19 (VSSLCM14), U2.F2 (VSSLCN15), U2.F19 (VSSLCN16), U2.K2 (VSSLSC17), U2.K19 (VSSLSC18), U2.L3 (VSSHCM19), U2.L18 (VSSHCM20), U2.T2 (VSSLCN21), U2.T19 (VSSLCN22), U2.U2 (VSSLCM23), U2.U19 (VSSLCM24), U2.V2 (VSSLSA25), U2.V19 (VSSLSA26), U2.W4 (VSSHPX27), U2.W6 (VSSLPL28), U2.W8 (VSSLPLD29), U2.W9 (VSSLPLA30), U2.W10 (VSSLIF31), U2.W11 (VSSLIF32), U2.W12 (VSSLIF33), U2.W16 (VSSHDA34), U2.W17 (VSSHPX35), U2.Y5 (VSSLPLD36), U2.Y6 (VSSLSC37), U2.Y16 (VSSLSC38), U3.2 (GND), U4.4 (GND), U4.11 (GND), U5.2 (GND), U6.2 (GND), U6.3 (ALERT), U6.4 (ADD0), U7.2 (GND), U8.1 (AP_SDO/AP_AD0), U8.2 (RESV_2), U8.3 (RESV_3), U8.6 (GND), U8.7 (RESV_7), U8.10 (RESV_10), U8.11 (RESV_11)
unnamed: C1.1, U2.C16 (VLOADCMSF)
unnamed: C3.1, U2.D5 (VLOADLM)
unnamed: C4.1, U2.D16 (VLOADLM)
unnamed: C8.1, U2.C5 (VLOADCMSF)
unnamed: JP1.2 (B), U2.W5 (SLASEL)
unnamed: R3.2, R4.1, U1.5 (FB)
unnamed: L1.1, U1.3 (SW)
unnamed: C15.1, FB3.1, U1.4 (VIN)
unnamed: C2.1, U2.V15 (VBGR1)
unnamed: C9.1, U2.C14 (VBGR2)
unnamed: R2.1, U2.V14 (VEXRES1)
unnamed: R1.1, U2.D13 (VEXRES2)
unnamed: C6.1, U2.D10 (VRLS)
unnamed: C7.1, U2.D11 (VRLT)
unnamed: C5.1, U2.D9 (VRLT_RD)
unnamed: C10.2, FB1.2, U3.1 (IN)
unnamed: C68.1, R11.1, R12.2, U4.3 (FB)
unnamed: C67.1, U4.8 (NR/SS)
unnamed: C11.3, C14.1, U4.6 (SS_CTRL), U4.9 (IN), U4.10 (IN)
unnamed: R5.2, U5.3 (Out)
unnamed: C70.2, FB2.2, U6.5 (V+)
RST_1V8: R8.2, TP10.1, U2.P19 (XCLR)
SCL_1V8: U2.P20 (SCK), U7.5 (SCL_A), U8.13 (AP_SCL/AP_SCLK)
SCL_3V3: J1.4, J9.20, U6.1 (SCL), U7.8 (SCL_B)
SDA_1V8: U2.R20 (SDI), U7.4 (SDA_A), U8.14 (AP_SDA/AP_SDIO/AP_SDI)
SDA_3V3: J1.3, J9.21, U6.6 (SDA), U7.1 (SDA_B)
XHS: J4.1 (In), U2.N20 (XHS)
XVS: J3.1 (In), U2.L20 (XVS), U8.9 (INT2/FSYNC/CLKIN)

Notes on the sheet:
Temperature Sensor
VDDLPL
VDDLCM
VDDLCN
I2C Level Shifter
VDDHPX
VDDMIO
VDDHCM
Power
I2C ADDR: 0x68
VDDHDA
VDDHCP
I2C ADDR: 0x48
VDDLSA
Connector
VDDLSC
MISC
VDDLIF
IMX294
VDDLPLD
IMU
IMX294 Decoupling Caps
VDDSUB
QWIIC
VDDLPLA

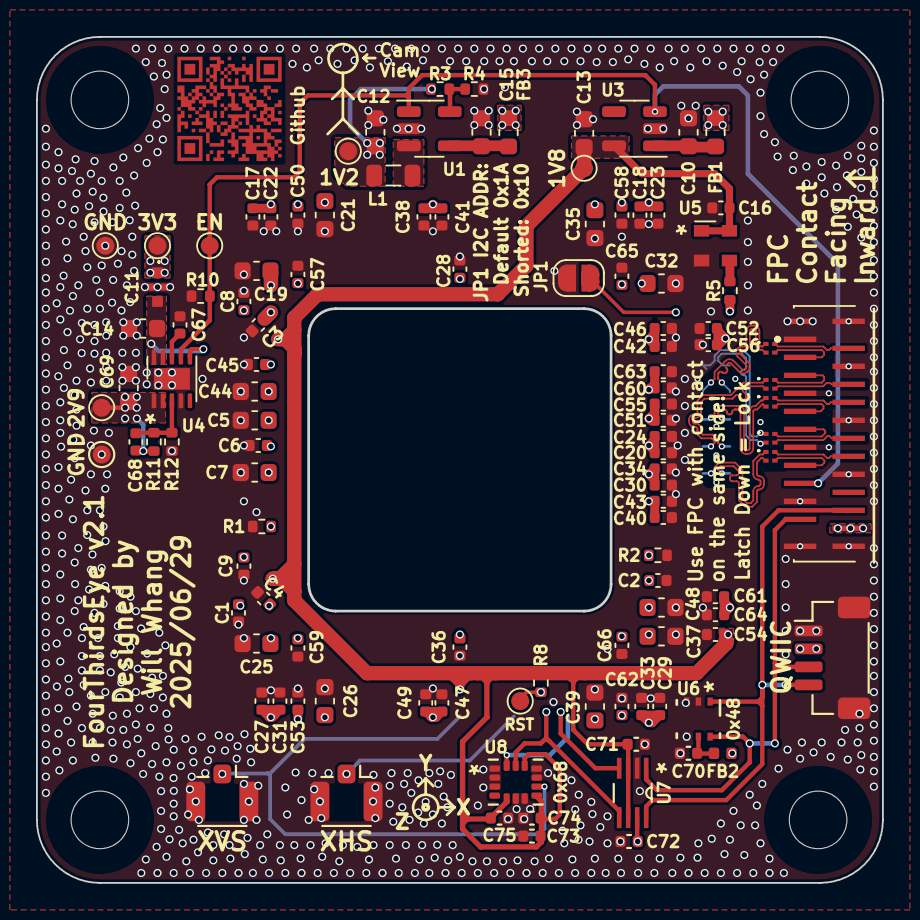
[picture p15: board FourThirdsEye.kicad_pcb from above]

Board: 4 copper layers, 47.0 x 47.0 mm, 118 parts (1 on the bottom side), 55 nets.

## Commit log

2025-11-24 Uploading 3D model for the v2.1 board
    Let's see how Github renders this STL.....
    [FourthirdEye_withSensor_V2.1.step, FourthirdEye_withSensor_V2.1.stl]
2025-11-24 upload V2.1 files and Cmount adaptor 3D model
    [BOM_IMX294.xlsx, Cmount_BackPlate.step, Cmount_FrontPlate.step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]
